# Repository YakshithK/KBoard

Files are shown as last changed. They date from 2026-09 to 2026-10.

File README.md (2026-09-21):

# KBoard

An 84-key custom mechanical keyboard built from scratch around the RP2040. No dev module: the RP2040, flash, regulator, USB-C, crystal, and support circuitry are all on the board. Uses Cherry MX Browns.

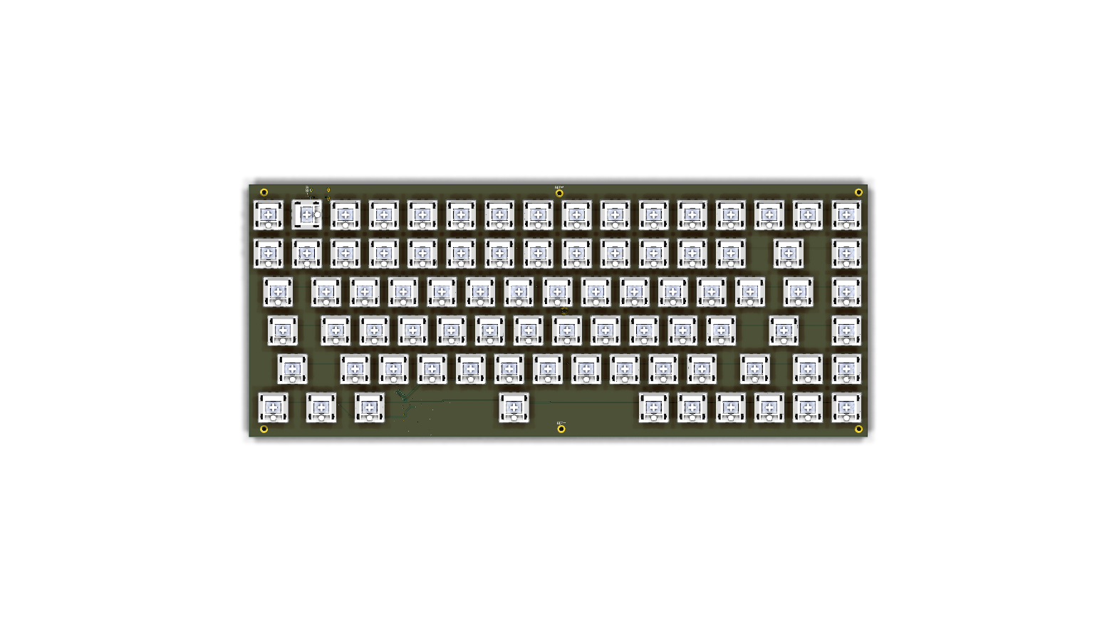
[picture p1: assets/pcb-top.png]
KBoard PCB top render


| Top | Bottom |
| --- | --- |
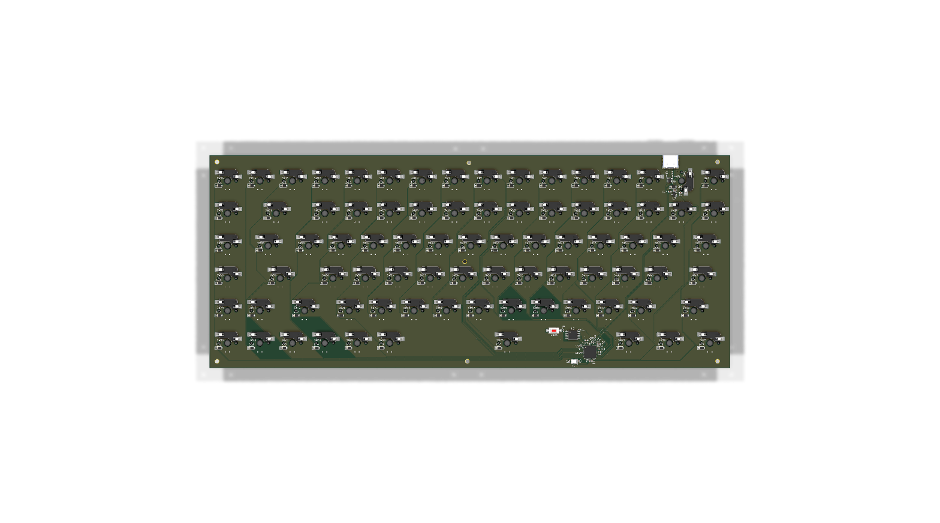
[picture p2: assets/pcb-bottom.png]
PCB bottom view
| PCB top view |  |

## Features
- 84 hot-swap MX-compatible switches in a ROW2COL matrix with per-key diodes
- From-scratch RP2040 design with USB-C, 16Mbit flash, and onboard 3.3V regulation
- QMK firmware with RP2040 USB bootloader (drag-and-drop UF2 flashing)

## Technical Details

The PCB is a basic 2-layer pcb (306 x 125 mm) using an RP2040 SoC with a USB-C connector. There's also a switch broken on the bottom for boot/reset.

Schematic

## Bill of Materials

Please see: [`BOM.csv`](BOM.csv)

## Repo Index

### Start Here

| Path | Purpose |
| --- | --- |
| [`README.md`](README.md) | Project overview, features, bill of materials, and this repository map |
| [`BOM.csv`](BOM.csv) | Bill of materials |

### Hardware: KiCad

| Path | Purpose |
| --- | --- |
| [`kboard_pcb/KBoard.kicad_pro`](kboard_pcb/KBoard.kicad_pro) | KiCad project settings |
| [`kboard_pcb/KBoard.kicad_sch`](kboard_pcb/KBoard.kicad_sch) | Source schematic |
| [`kboard_pcb/KBoard.kicad_pcb`](kboard_pcb/KBoard.kicad_pcb) | Source PCB layout |

### Hardware: CAD Files

| Path | Purpose |
| --- | --- |
| [`CAD/KBoard.step`](CAD/KBoard.step) | 3D CAD model in STEP format |
| [`PCB/KBoard.step`](PCB/KBoard.step) | 3D CAD model in STEP format |
| [`PCB/KBoard.stl`](PCB/KBoard.stl) | 3D CAD model in STL format (local only, too large for git) |

### Hardware: Production Files

| Path | Purpose |
| --- | --- |
| [`production/KBoard-gerbers.zip`](production/KBoard-gerbers.zip) | Zipped Gerbers + drill, ready to upload to the fab |
| [`production/KBoard.step`](production/KBoard.step) | STEP model bundled for fabrication |
| [`production/gerbers/`](production/gerbers/) | Gerber plot, drill, and pick-and-place files |
| [`production/firmware/`](production/firmware/) | QMK firmware source and built UF2 for flashing |

### Hardware: Visual References

| Path | Purpose |
| --- | --- |
| [`assets/schematic.svg`](assets/schematic.svg) | Schematic preview |
| [`assets/pcb-top.png`](assets/pcb-top.png) | Top-side PCB render |
| [`assets/pcb-bottom.png`](assets/pcb-bottom.png) | Bottom-side PCB render |

### Firmware: QMK

| Path | Purpose |
| --- | --- |
| [`firmware/kboard/keyboard.json`](firmware/kboard/keyboard.json) | Keyboard identity, RP2040 target, pins, matrix, and layout |
| [`firmware/kboard/rules.mk`](firmware/kboard/rules.mk) | QMK build settings |
| [`firmware/kboard/config.h`](firmware/kboard/config.h) | Board configuration |
| [`firmware/kboard/kboard.h`](firmware/kboard/kboard.h) | Keyboard header included by QMK |
| [`firmware/kboard/keymaps/default/keymap.c`](firmware/kboard/keymaps/default/keymap.c) | Default keymap |

Build the firmware with `qmk compile -kb kboard -km default` (the `firmware/kboard` folder must be linked or copied to `qmk_firmware/keyboards/kboard`). Flash the resulting UF2, also bundled at [`production/firmware/kboard_default.uf2`](production/firmware/kboard_default.uf2), by double-pressing reset and dragging it onto the USB drive.

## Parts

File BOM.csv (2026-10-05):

Item Name | Qty | Price (total) (USD) | Item link | Notes
U1 - RP2040 microcontroller QFN-56 (Raspberry Pi) | 1 | $4.99 | https://www.lcsc.com/product-detail/C2040.html | LCSC C2040 - 5pcs
U2 - W25Q16JVSSIQ 16Mbit SPI flash SOIC-8 (Winbond) | 1 | $6.08 | https://www.lcsc.com/product-detail/FLASH_W25Q16JVSSIQ_C82317.html | LCSC C82317 - 5pcs
U3 - XC6206P332MR-G 3.3V LDO SOT-23-3 (Torex) | 1 | $0.72 | https://www.lcsc.com/product-detail/Voltage-Regulators-Linear-Low-Drop-Out-LDO-Regulators_Torex-Semicon-XC6206P332MR-G_C5446.html | LCSC C5446 - MOQ 5
U4 - USBLC6-2SC6 USB ESD protection SOT-23-6 (ST) | 1 | $0.89 | https://www.lcsc.com/product-detail/C7519.html | LCSC C7519
Y1 - 12MHz crystal 3225 12pF load (LIMING) | 1 | $0.49 | https://www.lcsc.com/product-detail/Crystals_Suzhou-Liming-Elec-3225-12-00-12-10-10-A_C518158.html | LCSC C518158 - 5pcs
J2 - TYPE-C 16PIN 2MD(073) USB-C receptacle (SHOU HAN) | 1 | $0.35 | https://www.lcsc.com/product-detail/USB-Connectors_SHOU-HAN-TYPE-C-16PIN-2MD-073_C2765186.html | LCSC C2765186 - pad-identical to GCT USB4105 footprint verified ±4.32mm shell legs
F1 - 0402L050SLKR PTC fuse 6V 500mA 0402 (Littelfuse) | 1 | $1.37 | https://www.lcsc.com/product-detail/C206938.html | LCSC C206938 - MOQ 5
R1, R2 - Resistor 1k 0402 (Yageo) | 2 | $0.29 | https://www.lcsc.com/product-detail/C105637.html | LCSC C105637 - 100pcs
R3, R4 - Resistor 27R 0402 (Yageo 1%) | 2 | $0.10 | https://www.lcsc.com/product-detail/C138021.html | LCSC C138021 - in-stock alt for backordered JR part
R5, R6 - Resistor 5.1k 0402 (Yageo) | 2 | $0.21 | https://www.lcsc.com/product-detail/C105873.html | LCSC C105873 - 100pcs
C1-C10 - Capacitor 0.1uF 0402 MLCC (KEMET) | 10 | $2.40 | https://www.lcsc.com/product-detail/C169842.html | LCSC C169842
C11-C12 - Capacitor 15pF 0402 MLCC crystal load (Murata) | 2 | $0.11 | https://www.lcsc.com/product-detail/C76950.html | LCSC C76950 - 100pcs
C13-C16 - Capacitor 1uF 0603 MLCC (Yageo) | 4 | $0.64 | https://www.lcsc.com/product-detail/C106248.html | LCSC C106248
C17 - Capacitor 10uF 0603 MLCC (Murata) | 1 | $0.82 | https://www.lcsc.com/product-detail/C2959727.html | LCSC C2959727
D1-D84 - 1N4148W switching diode SOD-123 | 84 | $4.15 | https://www.lcsc.com/product-detail/Switching-Diode_MDD-Microdiode-Electronics-1N4148W_C84367.html | LCSC C84367 - 500pcs
SW85 - RS-282G05A3-SM RT tactile switch (C&K) | 1 | $6.77 | https://www.lcsc.com/product-detail/C221930.html | LCSC C221930
HS1-HS84 - Kailh CPG151101S11 hot-swap socket | 84 | $12.50 | https://www.aliexpress.com/ | 110-pc pack - AliExpress
SW1-SW84 - Mechanical switch 3-pin MX (Unikeys) | 68 | $24.00 | https://unikeyboards.com/ | 7x10-packs - 16 already owned
TX AP - Plate mount stabilizer kit 1.6mm TKL | 1 | $12.30 | https://unikeyboards.com/products/tx-ap-stabilizers-rev-4-almost-perfect-edition | 1x6.25u + 4x2u wires - covers 6.25u 2u 2.25u
PETG filament 1.75mm 1kg | 1 | $15.50 | https://www.aliexpress.com/ | Case halves + printed keycaps
M2 inserts screws kit | 1 | $1.03 | https://www.aliexpress.com/ | AliExpress 500pc kit
PCB1 - KBoard PCB 2-layer 306x125mm | 1 | $30.24 | https://jlcpcb.com/ | 5 pcs + aluminium plate - uploaded production/KBoard-gerbers.zip
Total Price (USD): |  | $125.95 |  | Excludes shipping duties tools and case hardware subtotals

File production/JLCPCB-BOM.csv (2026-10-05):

Comment | Designator | Footprint | JLCPCB Part #
RP2040 | U1 | QFN-56-1EP_7x7mm_P0.4mm_EP3.2x3.2mm
W25Q16JVSSIQ | U2 | SOIC-8_5.3x5.3mm_P1.27mm | C82317
XC6206P332MR-G | U3 | SOT-23-3 | C5446
USBLC6-2SC6 | U4 | SOT-23-6
Crystal 12MHz 3225 12pF | Y1 | Crystal_SMD_3225-4Pin_3.2x2.5mm | C518158
USB4105-GF-A | J2 | GCT_USB4105-GF-A
0402L050SLKR | F1 | Fuse_0402_1005Metric | C206938
Resistor 1k 0402 | R1,R2 | C_0402_1005Metric
Resistor 27R 0402 | R3,R4 | C_0402_1005Metric
Resistor 5.1k 0402 | R5,R6 | C_0402_1005Metric
Capacitor 0.1uF 0402 | C1,C2,C3,C4,C5,C6,C7,C8,C9,C10 | C_0402_1005Metric
Capacitor 15pF 0402 | C11,C12 | C_0402_1005Metric
Capacitor 1uF 0603 | C13,C14,C15,C16 | C_0603_1608Metric
Capacitor 10uF 0603 | C17 | C_0603_1608Metric
1N4148W | D1,D2,D3,D4,D5,D6,D7,D8,D9,D10,D11,D12,D13,D14,D15,D16,D17,D18,D19,D20,D21,D22,D23,D24,D25,D26,D27,D28,D29,D30,D31,D32,D33,D34,D35,D36,D37,D38,D39,D40,D41,D42,D43,D44,D45,D46,D47,D48,D49,D50,D51,D52,D53,D54,D55,D56,D57,D58,D59,D60,D61,D62,D63,D64,D65,D66,D67,D68,D69,D70,D71,D72,D73,D74,D75,D76,D77,D78,D79,D80,D81,D82,D83,D84 | D_SOD-123 | C84367
CPG151101S11-16 | SW1,SW2,SW3,SW4,SW5,SW6,SW7,SW8,SW9,SW10,SW11,SW12,SW13,SW14,SW15,SW16,SW17,SW18,SW19,SW20,SW21,SW22,SW23,SW24,SW25,SW26,SW27,SW28,SW29,SW30,SW31,SW32,SW33,SW34,SW35,SW36,SW37,SW38,SW39,SW40,SW41,SW42,SW43,SW44,SW45,SW46,SW47,SW48,SW49,SW50,SW51,SW52,SW53,SW54,SW55,SW56,SW57,SW58,SW59,SW60,SW61,SW62,SW63,SW64,SW65,SW66,SW67,SW68,SW69,SW70,SW71,SW72,SW73,SW74,SW75,SW76,SW77,SW78,SW79,SW80,SW81,SW82,SW83,SW84 | SW_MX_HS_CPG151101S11_1u | C9900155050
RS-282G05A3-SM RT | SW85 | SW_SPST_CK_RS282G05A3

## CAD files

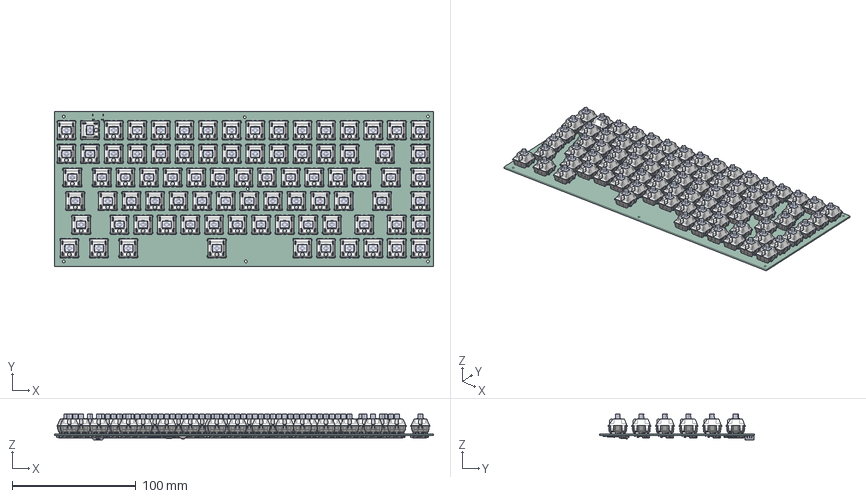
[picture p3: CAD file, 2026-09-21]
CAD/KBoard.step
306.0 x 125.0 x 20.8 mm
D_SOD-123 x 84
Contact x 168
Bottom x 84
Pulsador x 84
Top x 84
Pieza5^Cherry MX x 84
Pin1 x 84
Pin2 x 84
Led 3mm_trans x 84
C_0603_1608Metric x 5
C_0402_1005Metric x 18
SW_SPST_CK_RS282G05A3
USB4105
SOIC-8_5.3x5.3mm_P1.27mm
QFN-56-1EP_7x7mm_P0.4mm_EP3.2x3.2mm
SOT-23-6
Crystal_SMD_3225-4Pin_3.2x2.5mm
Fuse_0402_1005Metric
SOT-23-3
KBoard_PCB

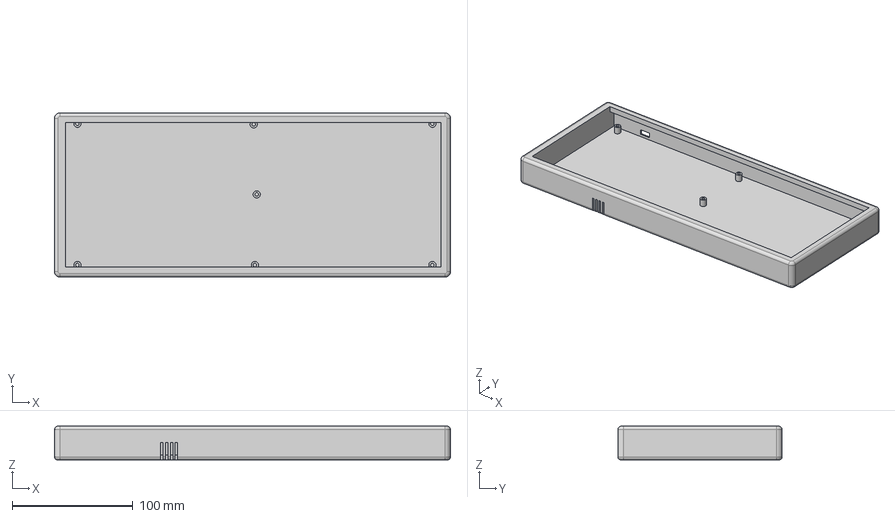
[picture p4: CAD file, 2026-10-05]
KBoard_Case.step
328.0 x 136.0 x 28.0 mm

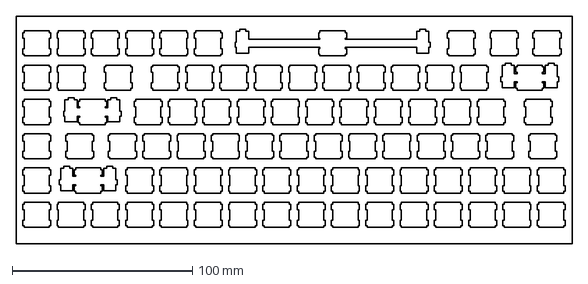
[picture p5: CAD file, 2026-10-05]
plate.dxf.dxf
308.8 x 126.3 mm

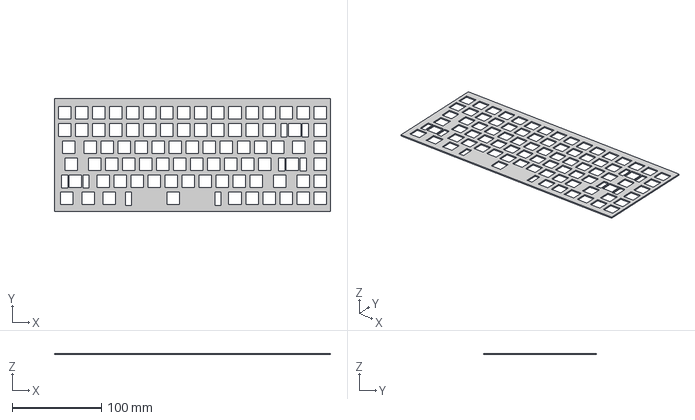
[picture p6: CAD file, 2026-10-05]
Kboard_plate.step
308.8 x 126.3 x 1.50 mm

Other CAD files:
PCB/KBoard.stl

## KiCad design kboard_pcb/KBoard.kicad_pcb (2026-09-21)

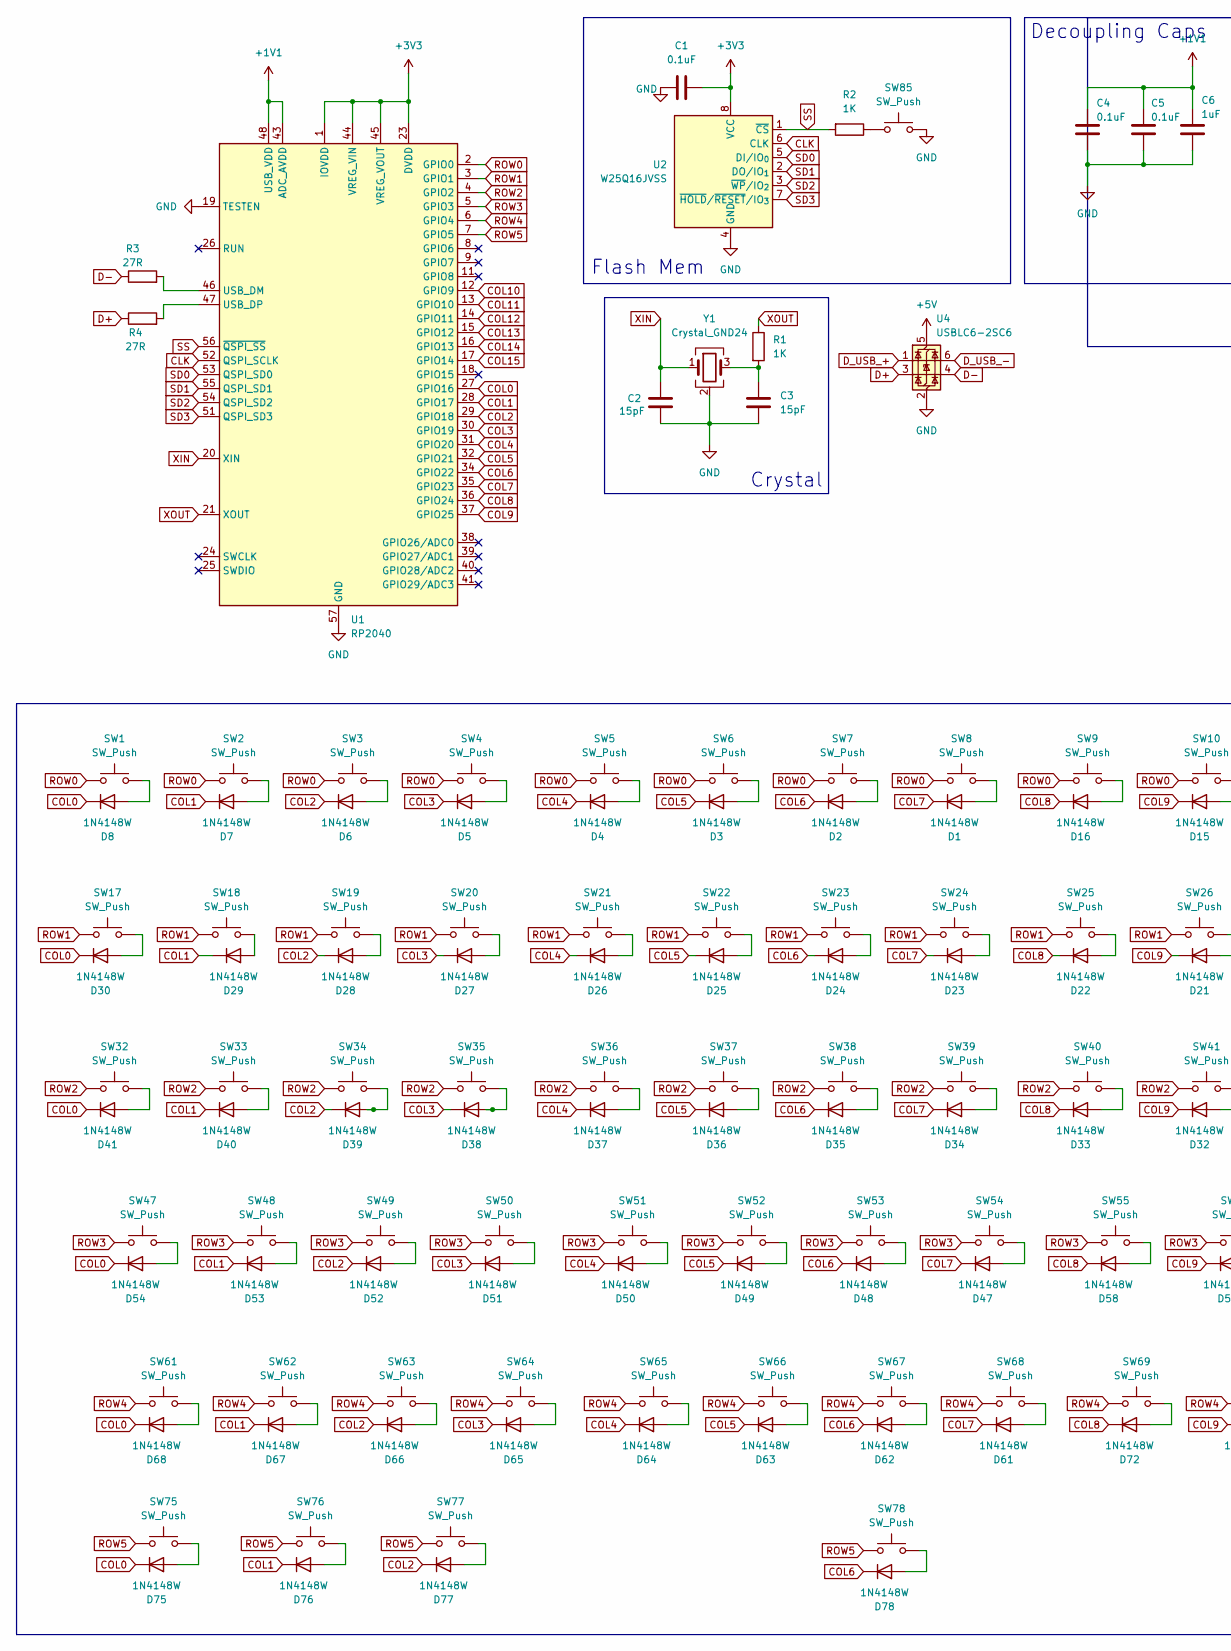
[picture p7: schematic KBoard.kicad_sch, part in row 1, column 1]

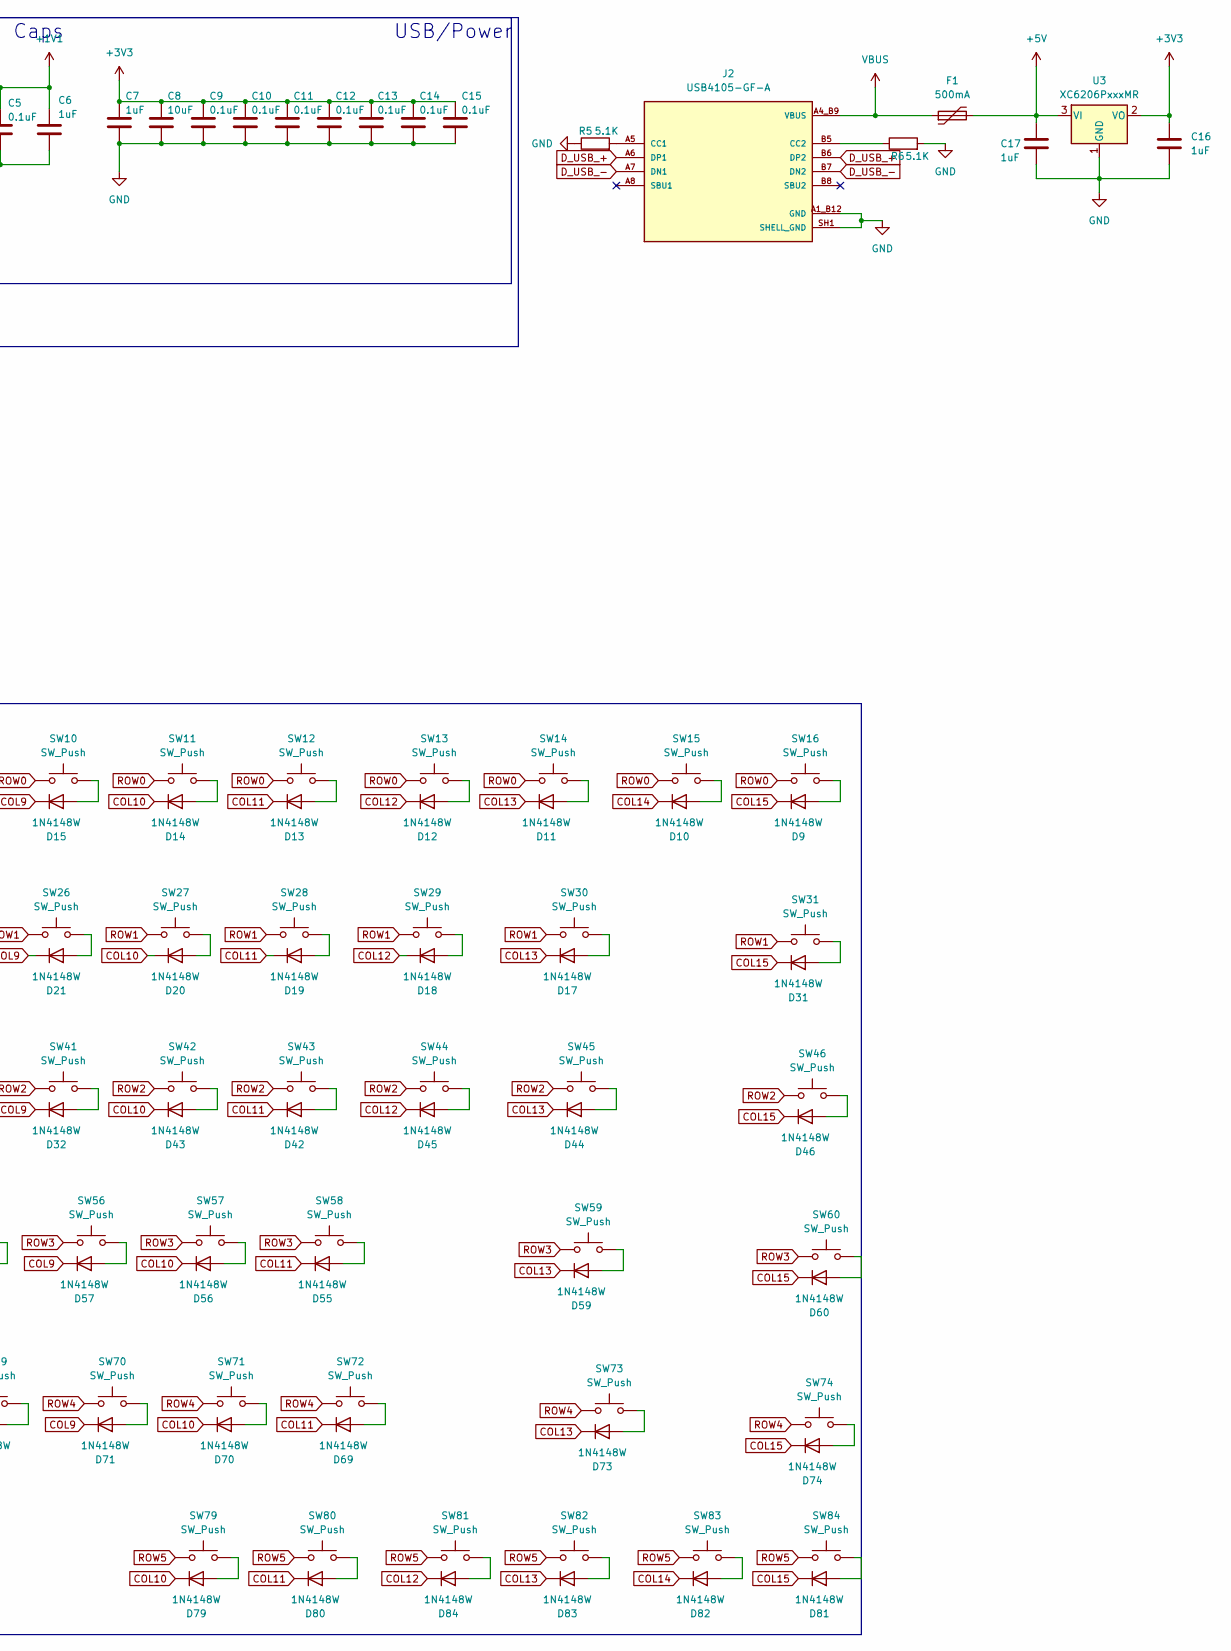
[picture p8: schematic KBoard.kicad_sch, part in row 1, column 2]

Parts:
C1, C4, C5, C9, C10, C11, C12, C13, C14, C15: 0.1uF; C_0402_1005Metric
C2, C3: 15pF; C_0402_1005Metric
C6, C7, C16, C17: 1uF; C_0603_1608Metric
C8: 10uF; C_0603_1608Metric
D1, D2, D3, D4, D5, D6, D7, D8, D9, D10, D11, D12, D13, D14, D15, D16, D17, D18, D19, D20, D21, D22, D23, D24, D25, D26, D27, D28, D29, D30, D31, D32, D33, D34, D35, D36, D37, D38, D39, D40, D41, D42, D43, D44, D45, D46, D47, D48, D49, D50, D51, D52, D53, D54, D55, D56, D57, D58, D59, D60, D61, D62, D63, D64, D65, D66, D67, D68, D69, D70, D71, D72, D73, D74, D75, D76, D77, D78, D79, D80, D81, D82, D83, D84: 1N4148W; D_SOD-123
F1: 500mA; Fuse_0402_1005Metric
J2: USB4105-GF-A; GCT_USB4105-GF-A; PARTREV B4; DigiKey_Part_Number 2073-USB4105-GF-ACT-ND
R1, R2: 1K; C_0402_1005Metric
R3, R4: 27R; C_0402_1005Metric
R5, R6: 5.1K; C_0402_1005Metric
SW1, SW2, SW3, SW4, SW5, SW6, SW7, SW8, SW9, SW10, SW11, SW12, SW13, SW14, SW15, SW16, SW17, SW18, SW19, SW20, SW21, SW22, SW23, SW24, SW25, SW26, SW27, SW28, SW29, SW30, SW31, SW32, SW33, SW34, SW35, SW36, SW37, SW38, SW39, SW40, SW41, SW42, SW43, SW44, SW45, SW46, SW47, SW48, SW49, SW50, SW51, SW52, SW53, SW54, SW55, SW56, SW57, SW58, SW59, SW60, SW61, SW62, SW63, SW64, SW65, SW66, SW67, SW68, SW69, SW70, SW71, SW72, SW73, SW74, SW75, SW76, SW77, SW78, SW79, SW80, SW81, SW82, SW83, SW84: SW_Push; SW_MX_HS_CPG151101S11_1u
SW85: SW_Push; SW_SPST_CK_RS282G05A3
U1: RP2040; QFN-56-1EP_7x7mm_P0.4mm_EP3.2x3.2mm
U2: W25Q16JVSS; SOIC-8_5.3x5.3mm_P1.27mm
U3: XC6206PxxxMR; SOT-23-3
U4: USBLC6-2SC6; SOT-23-6
Y1: Crystal_GND24; Crystal_SMD_3225-4Pin_3.2x2.5mm

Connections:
+1V1: C4.1, C5.1, C6.1, U1.43 (ADC_AVDD), U1.48 (USB_VDD)
+3V3: C1.2, C7.1, C8.1, C9.1, C10.1, C11.1, C12.1, C13.1, C14.1, C15.1, C16.1, U1.1 (IOVDD), U1.10 (IOVDD), U1.22 (IOVDD), U1.23 (DVDD), U1.33 (IOVDD), U1.42 (IOVDD), U1.44 (VREG_VIN), U1.45 (VREG_VOUT), U1.49 (IOVDD), U1.50 (DVDD), U2.8 (VCC), U3.2 (VO)
+5V: C17.1, F1.2, U3.3 (VI), U4.5 (VBUS)
CLK: U1.52 (QSPI_SCLK), U2.6 (CLK)
COL0: D8.1 (K), D30.1 (K), D41.1 (K), D54.1 (K), D68.1 (K), D75.1 (K), U1.27 (GPIO16)
COL1: D7.1 (K), D29.1 (K), D40.1 (K), D53.1 (K), D67.1 (K), D76.1 (K), U1.28 (GPIO17)
COL2: D6.1 (K), D28.1 (K), D39.1 (K), D52.1 (K), D66.1 (K), D77.1 (K), U1.29 (GPIO18)
COL3: D5.1 (K), D27.1 (K), D38.1 (K), D51.1 (K), D65.1 (K), U1.30 (GPIO19)
COL4: D4.1 (K), D26.1 (K), D37.1 (K), D50.1 (K), D64.1 (K), U1.31 (GPIO20)
COL5: D3.1 (K), D25.1 (K), D36.1 (K), D49.1 (K), D63.1 (K), U1.32 (GPIO21)
COL6: D2.1 (K), D24.1 (K), D35.1 (K), D48.1 (K), D62.1 (K), D78.1 (K), U1.34 (GPIO22)
COL7: D1.1 (K), D23.1 (K), D34.1 (K), D47.1 (K), D61.1 (K), U1.35 (GPIO23)
COL8: D16.1 (K), D22.1 (K), D33.1 (K), D58.1 (K), D72.1 (K), U1.36 (GPIO24)
COL9: D15.1 (K), D21.1 (K), D32.1 (K), D57.1 (K), D71.1 (K), U1.37 (GPIO25)
COL10: D14.1 (K), D20.1 (K), D43.1 (K), D56.1 (K), D70.1 (K), D79.1 (K), U1.12 (GPIO9)
COL11: D13.1 (K), D19.1 (K), D42.1 (K), D55.1 (K), D69.1 (K), D80.1 (K), U1.13 (GPIO10)
COL12: D12.1 (K), D18.1 (K), D45.1 (K), D84.1 (K), U1.14 (GPIO11)
COL13: D11.1 (K), D17.1 (K), D44.1 (K), D59.1 (K), D73.1 (K), D83.1 (K), U1.15 (GPIO12)
COL14: D10.1 (K), D82.1 (K), U1.16 (GPIO13)
COL15: D9.1 (K), D31.1 (K), D46.1 (K), D60.1 (K), D74.1 (K), D81.1 (K), U1.17 (GPIO14)
D+: R4.1, U4.3 (I/O2)
D-: R3.1, U4.4 (I/O2)
D_USB_+: J2.A6 (DP1), J2.B6 (DP2), U4.1 (I/O1)
D_USB_-: J2.A7 (DN1), J2.B7 (DN2), U4.6 (I/O1)
GND: C1.1, C2.2, C3.2, C4.2, C5.2, C6.2, C7.2, C8.2, C9.2, C10.2, C11.2, C12.2, C13.2, C14.2, C15.2, C16.2, C17.2, J2.A1_B12 (GND), J2.B1_A12 (GND), J2.SH1 (SHELL_GND), J2.SH2 (SHELL_GND), J2.SH3 (SHELL_GND), J2.SH4 (SHELL_GND), R5.1, R6.2, SW85.2, U1.19 (TESTEN), U1.57 (GND), U2.4 (GND), U3.1 (GND), U4.2 (GND), Y1.2 (G), Y1.4 (G)
unnamed: C3.1, R1.2, Y1.3
unnamed: D1.2 (A), SW8.2
unnamed: D2.2 (A), SW7.2
unnamed: D3.2 (A), SW6.2
unnamed: D4.2 (A), SW5.2
unnamed: D5.2 (A), SW4.2
unnamed: D6.2 (A), SW3.2
unnamed: D7.2 (A), SW2.2
unnamed: D8.2 (A), SW1.2
unnamed: D9.2 (A), SW16.2
unnamed: D10.2 (A), SW15.2
unnamed: D11.2 (A), SW14.2
unnamed: D12.2 (A), SW13.2
unnamed: D13.2 (A), SW12.2
unnamed: D14.2 (A), SW11.2
unnamed: D15.2 (A), SW10.2
unnamed: D16.2 (A), SW9.2
unnamed: D17.2 (A), SW30.2
unnamed: D18.2 (A), SW29.2
unnamed: D19.2 (A), SW28.2
unnamed: D20.2 (A), SW27.2
unnamed: D21.2 (A), SW26.2
unnamed: D22.2 (A), SW25.2
unnamed: D23.2 (A), SW24.2
unnamed: D24.2 (A), SW23.2
unnamed: D25.2 (A), SW22.2
unnamed: D26.2 (A), SW21.2
unnamed: D27.2 (A), SW20.2
unnamed: D28.2 (A), SW19.2
unnamed: D29.2 (A), SW18.2
unnamed: D30.2 (A), SW17.2
unnamed: D31.2 (A), SW31.2
unnamed: D32.2 (A), SW41.2
unnamed: D33.2 (A), SW40.2
unnamed: D34.2 (A), SW39.2
unnamed: D35.2 (A), SW38.2
unnamed: D36.2 (A), SW37.2
unnamed: D37.2 (A), SW36.2
unnamed: D38.2 (A), SW35.2
unnamed: D39.2 (A), SW34.2
unnamed: D40.2 (A), SW33.2
unnamed: D41.2 (A), SW32.2
unnamed: D42.2 (A), SW43.2
unnamed: D43.2 (A), SW42.2
unnamed: D44.2 (A), SW45.2
unnamed: D45.2 (A), SW44.2
unnamed: D46.2 (A), SW46.2
unnamed: D47.2 (A), SW54.2
unnamed: D48.2 (A), SW53.2
unnamed: D49.2 (A), SW52.2
unnamed: D50.2 (A), SW51.2
unnamed: D51.2 (A), SW50.2
unnamed: D52.2 (A), SW49.2
unnamed: D53.2 (A), SW48.2
unnamed: D54.2 (A), SW47.2
unnamed: D55.2 (A), SW58.2
unnamed: D56.2 (A), SW57.2
unnamed: D57.2 (A), SW56.2
unnamed: D58.2 (A), SW55.2
unnamed: D59.2 (A), SW59.2
unnamed: D60.2 (A), SW60.2
unnamed: D61.2 (A), SW68.2
unnamed: D62.2 (A), SW67.2
unnamed: D63.2 (A), SW66.2
unnamed: D64.2 (A), SW65.2
unnamed: D65.2 (A), SW64.2
unnamed: D66.2 (A), SW63.2
unnamed: D67.2 (A), SW62.2
unnamed: D68.2 (A), SW61.2
unnamed: D69.2 (A), SW72.2
unnamed: D70.2 (A), SW71.2
unnamed: D71.2 (A), SW70.2
unnamed: D72.2 (A), SW69.2
unnamed: D73.2 (A), SW73.2
unnamed: D74.2 (A), SW74.2
unnamed: D75.2 (A), SW75.2
unnamed: D76.2 (A), SW76.2
unnamed: D77.2 (A), SW77.2
unnamed: D78.2 (A), SW78.2
unnamed: D79.2 (A), SW79.2
unnamed: D80.2 (A), SW80.2
unnamed: D81.2 (A), SW84.2
unnamed: D82.2 (A), SW83.2
unnamed: D83.2 (A), SW82.2
unnamed: D84.2 (A), SW81.2
unnamed: J2.A5 (CC1), R5.2
unnamed: J2.B5 (CC2), R6.1
unnamed: R2.1, SW85.1
unnamed: R3.2, U1.46 (USB_DM)
unnamed: R4.2, U1.47 (USB_DP)
ROW0: SW1.1, SW2.1, SW3.1, SW4.1, SW5.1, SW6.1, SW7.1, SW8.1, SW9.1, SW10.1, SW11.1, SW12.1, SW13.1, SW14.1, SW15.1, SW16.1, U1.2 (GPIO0)
ROW1: SW17.1, SW18.1, SW19.1, SW20.1, SW21.1, SW22.1, SW23.1, SW24.1, SW25.1, SW26.1, SW27.1, SW28.1, SW29.1, SW30.1, SW31.1, U1.3 (GPIO1)
ROW2: SW32.1, SW33.1, SW34.1, SW35.1, SW36.1, SW37.1, SW38.1, SW39.1, SW40.1, SW41.1, SW42.1, SW43.1, SW44.1, SW45.1, SW46.1, U1.4 (GPIO2)
ROW3: SW47.1, SW48.1, SW49.1, SW50.1, SW51.1, SW52.1, SW53.1, SW54.1, SW55.1, SW56.1, SW57.1, SW58.1, SW59.1, SW60.1, U1.5 (GPIO3)
ROW4: SW61.1, SW62.1, SW63.1, SW64.1, SW65.1, SW66.1, SW67.1, SW68.1, SW69.1, SW70.1, SW71.1, SW72.1, SW73.1, SW74.1, U1.6 (GPIO4)
ROW5: SW75.1, SW76.1, SW77.1, SW78.1, SW79.1, SW80.1, SW81.1, SW82.1, SW83.1, SW84.1, U1.7 (GPIO5)
SD0: U1.53 (QSPI_SD0), U2.5 (DI/IO_{0})
SD1: U1.55 (QSPI_SD1), U2.2 (DO/IO_{1})
SD2: U1.54 (QSPI_SD2), U2.3 (~WP/IO_{2})
SD3: U1.51 (QSPI_SD3), U2.7 (~HOLD/~RESET/IO_{3})
SS: R2.2, U1.56 (~QSPI_SS), U2.1 (~CS)
VBUS: F1.1, J2.A4_B9 (VBUS), J2.B4_A9 (VBUS)
XIN: C2.1, U1.20 (XIN), Y1.1
XOUT: R1.1, U1.21 (XOUT)

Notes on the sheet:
Crystal
Flash Mem
USB/Power
Decoupling Caps

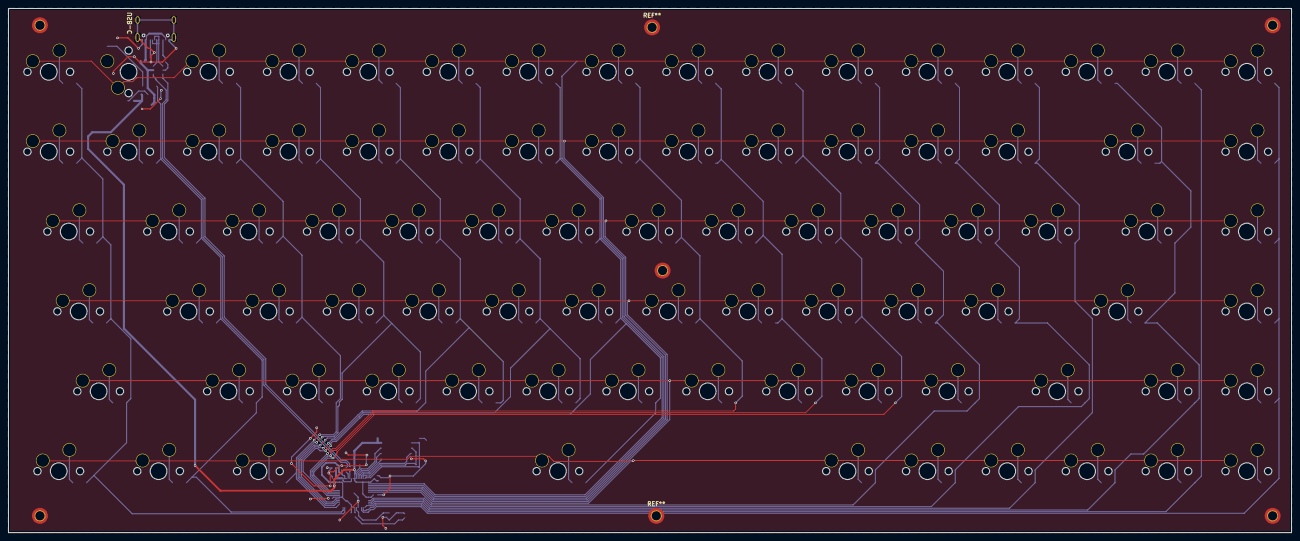
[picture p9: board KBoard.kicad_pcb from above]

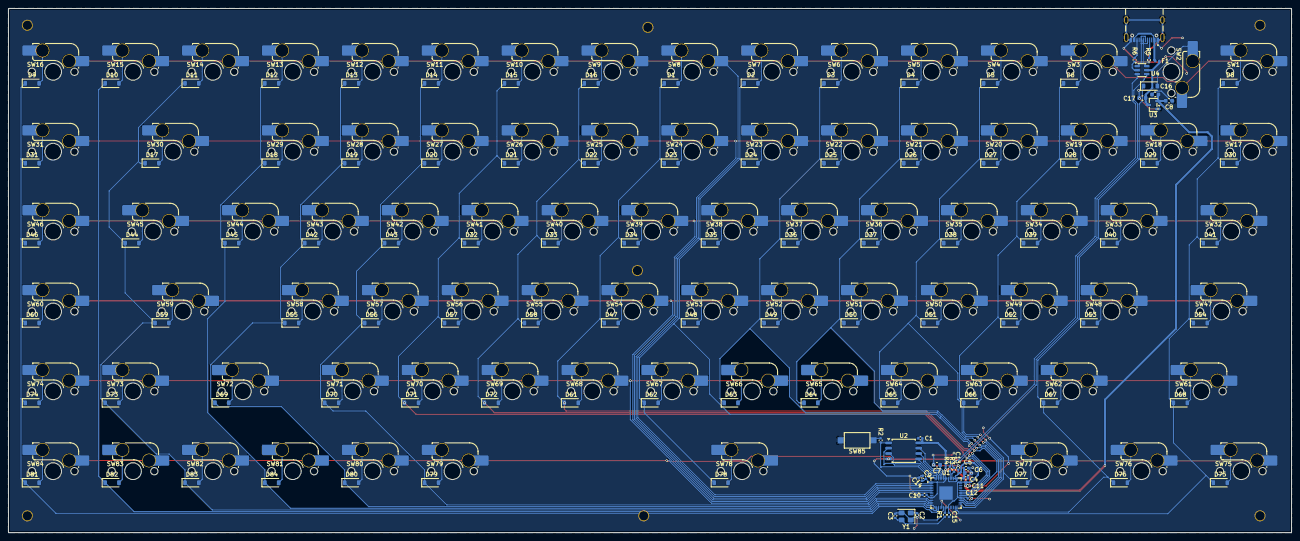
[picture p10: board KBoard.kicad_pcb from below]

Board: 2 copper layers, 306.0 x 125.0 mm, 199 parts (199 on the bottom side), 129 nets.

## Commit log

2026-09-21 Add KBoard PCB CAD and firmware
    [KBoard.kicad_pcb, KBoard.kicad_sch, KBoard.step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]
2026-09-21 add README with renders, BOM.csv, gerbers and zipped production files
    [BOM.csv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]
2026-09-21 added links to BOM and revise README
    [BOM.csv]
2026-10-05 update BOM to final LCSC sourcing and verified pricing; add JLCPCB quote files and case/plate CAD
    [BOM.csv, JLCPCB-BOM.csv, KBoard_Case.step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]
2026-10-05 source USB-C from LCSC C2765186 - pad-identical to GCT footprint, no DigiKey
    [BOM.csv]
